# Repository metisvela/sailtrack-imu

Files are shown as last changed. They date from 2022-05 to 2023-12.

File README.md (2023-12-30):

<p align="center">
  
</p>

<p align="center">
  
  
</p>

# SailTrack IMU

SailTrack IMU is a component of the SailTrack system, it manages IMU data, providing attitude information of the boat. To learn more about the SailTrack project, please visit the [project repository](https://github.com/metisvela/sailtrack).

The SailTrack IMU module is based on a battery powered LilyGo TTGO T7, consisting of an [ESP32](https://www.espressif.com/en/products/socs/esp32) microcontroller, connected to an IMU breakout board. For a more detailed hardware description of the module, please refer to the [Bill Of Materials](hardware/BOM.csv). The 3D-printable enclosure con be found [here](hardware/STL).

The module performs the following tasks:

* It gets the IMU data coming from the accelerometer, gyrocope and magnetometer, and fuses them, using a Kalman filter, to obtain accurate and clean attitude infromation of the boat. The filtered metrics are then sent to the SailTrack Network.

<p align="center">
  <br/>
  
</p>

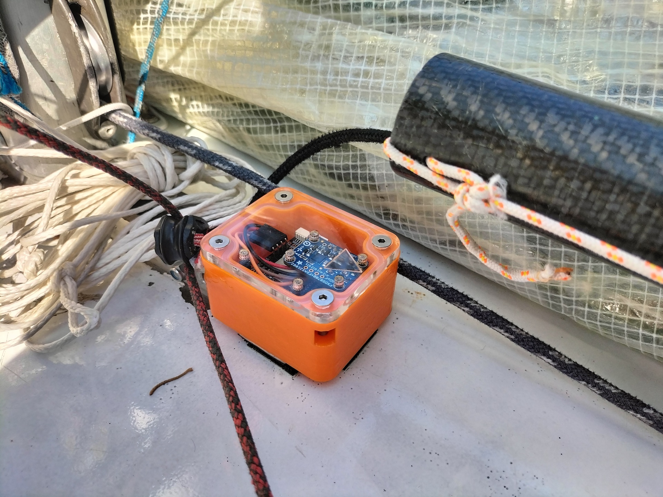
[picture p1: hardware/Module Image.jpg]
module-image


## Installation

Follow the instructions below to get the SailTrack IMU firmware correctly installed. If you encounter any problem, please [open an issue](https://github.com/metisvela/sailtrack-imu/issues/new).

1. [Install PlatformIO Core](https://docs.platformio.org/en/latest/core/installation/index.html).
2. Clone the SailTrack IMU repository:
   ```
   git clone https://github.com/metisvela/sailtrack-imu.git 
   ``` 
3. Cd into the directory:
   ```
   cd sailtrack-imu
   ```
4. **(macOS ONLY)** Uncomment the commented lines after "Patch for macOS" in the `platformio.ini` file.
5. Connect the module with an USB cable.
6. **(OPTIONAL BUT HIGHLY RECCOMENDED)** Calibrate the IMU:
   1. [Install MotionCal](https://www.pjrc.com/store/prop_shield.html).
   2. Flash the calibration firmware:
      ```
      pio run -e motioncal.cpp
      ```
   3. Open MotionCal and select the serial port the module is connected to.
   4. Start rotating the module doing circular movements in all possible directions until the `Gaps` value gets below 1%.
   5. Press the `Send Cal` button and wait until a green check appears. *Note: if the check doesn't appear after some seconds, press the `Send Cal` button again.*
7. Finally, flash the firmware:
   ```
   pio run
   ```

## Usage

Once the firmware is uploaded the module can work with the SailTrack system. When SailTrack IMU is turned on, a LED start to blink to notify the user about the connection status with SailTrack Core. Then, if the connection is successful, the LED stays on, otherwise the module will put itself to sleep, and it will try to connect later. Once the module is connected it will automatically start sending measurements.

## Contributing

Contributors are welcome. If you are a student of the University of Padova, please apply for the Metis Sailing Team team in the [website](http://metisvela.dii.unipd.it), specifying in the appliaction form that you are interested in contributing to the SailTrack Project. If you are not a student of the University of Padova, feel free to open Pull Requests and Issues to contribute to the project.

## License

Copyright © 2023, [Metis Sailing Team](https://github.com/metisvela). SailTrack IMU is available under the [GPL-3.0 license](https://www.gnu.org/licenses/gpl-3.0.en.html). See the LICENSE file for more info.

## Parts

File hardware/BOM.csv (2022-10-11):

Part Name | Total Quantity Required | Note
LilyGo TTGO T7 v1.3 ESP32-WROVER-B + BMS | 1
Adafruit Precision NXP 9-DOF Breakout Board - FXOS8700 + FXAS21002 | 1
103040 LiPo Battery 1S 1200mAh | 1

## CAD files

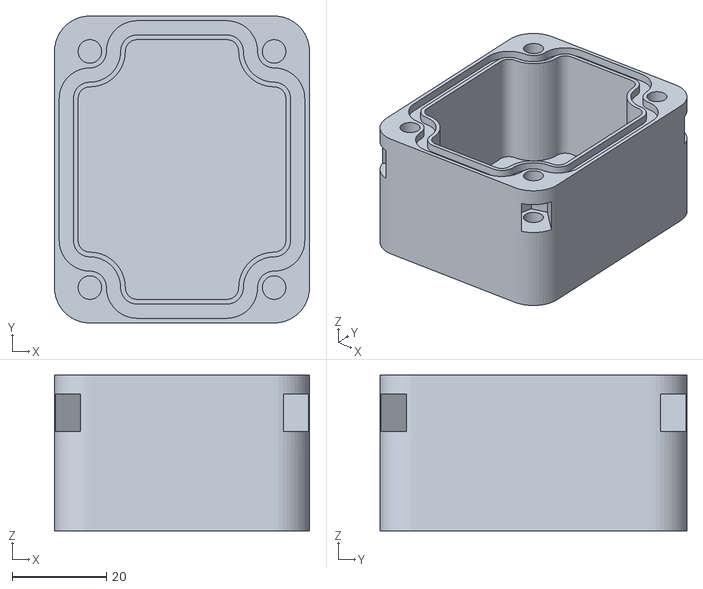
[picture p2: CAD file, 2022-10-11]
hardware/STL/Case Bottom.stl
54.0 x 65.0 x 33.0

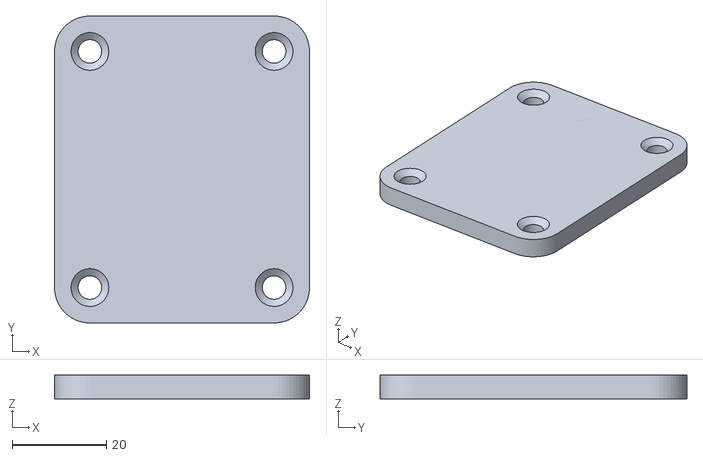
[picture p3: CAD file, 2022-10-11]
hardware/STL/Case Top.stl
54.0 x 65.0 x 5.00

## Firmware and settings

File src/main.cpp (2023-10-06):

#include <Arduino.h>
#include <SPI.h>
#include <SailtrackModule.h>
#include <Adafruit_FXOS8700.h>
#include <Adafruit_FXAS21002C.h>
#include <Adafruit_AHRS.h>
#include <Adafruit_Sensor_Calibration.h>

// -------------------------- Configuration -------------------------- //

#define MQTT_PUBLISH_FREQ_HZ		5
#define AHRS_UPDATE_FREQ_HZ			100

#define BATTERY_ADC_PIN 			35
#define BATTERY_ADC_RESOLUTION 		4095
#define BATTERY_ADC_REF_VOLTAGE 	1.1
#define BATTERY_ESP32_REF_VOLTAGE	3.3
#define BATTERY_NUM_READINGS 		32
#define BATTERY_READING_DELAY_MS	20

#define I2C_SDA_PIN 				27
#define I2C_SCL_PIN 				25

#define LOOP_TASK_INTERVAL_MS		1000 / AHRS_UPDATE_FREQ_HZ
#define MQTT_TASK_INTERVAL_MS	 	1000 / MQTT_PUBLISH_FREQ_HZ

// ------------------------------------------------------------------- //

SailtrackModule stm;
Adafruit_FXOS8700 fxos = Adafruit_FXOS8700(0x8700A, 0x8700B);
Adafruit_FXAS21002C fxas = Adafruit_FXAS21002C(0x0021002C);
Adafruit_NXPSensorFusion filter;
Adafruit_Sensor_Calibration_EEPROM cal;
Adafruit_Sensor *accelerometer, *gyroscope, *magnetometer;

float eulerX, eulerY, eulerZ;
float linearAccelX, linearAccelY, linearAccelZ;

class ModuleCallbacks: public SailtrackModuleCallbacks {
	void onStatusPublish(JsonObject status) {
		JsonObject battery = status.createNestedObject("battery");
		float avg = 0;
		for (int i = 0; i < BATTERY_NUM_READINGS; i++) {
			avg += analogRead(BATTERY_ADC_PIN) / BATTERY_NUM_READINGS;
			delay(BATTERY_READING_DELAY_MS);
		}
		battery["voltage"] = 2 * avg / BATTERY_ADC_RESOLUTION * BATTERY_ESP32_REF_VOLTAGE * BATTERY_ADC_REF_VOLTAGE;
	}
};

void mqttTask(void * pvArguments) {
	TickType_t lastWakeTime = xTaskGetTickCount();
	while (true) {
		StaticJsonDocument<STM_JSON_DOCUMENT_MEDIUM_SIZE> doc;

		JsonObject euler = doc.createNestedObject("euler");
		euler["x"] = eulerX;
		euler["y"] = eulerY;
		euler["z"] = eulerZ;

		JsonObject linearAccel = doc.createNestedObject("linearAccel");
		linearAccel["x"] = linearAccelX;
		linearAccel["y"] = linearAccelY;
		linearAccel["z"] = linearAccelZ;

		stm.publish("sensor/imu0", doc.as<JsonObjectConst>());

		vTaskDelayUntil(&lastWakeTime, pdMS_TO_TICKS(MQTT_TASK_INTERVAL_MS));
	}
}

void beginIMU() {
	Wire.setPins(I2C_SDA_PIN, I2C_SCL_PIN);
	fxos.begin();
	fxas.begin();
	accelerometer = fxos.getAccelerometerSensor();
	gyroscope = &fxas;
  	magnetometer = fxos.getMagnetometerSensor();
	Wire.setClock(400000);
}

void beginAHRS() {
	cal.begin();
	cal.loadCalibration();
	filter.begin(AHRS_UPDATE_FREQ_HZ);
}

void setup() {
	stm.begin("imu", IPAddress(192, 168, 42, 102), new ModuleCallbacks());
	beginIMU();
	beginAHRS();
	xTaskCreate(mqttTask, "mqttTask", STM_TASK_MEDIUM_STACK_SIZE, NULL, STM_TASK_MEDIUM_PRIORITY, NULL);
}

void loop() {
	TickType_t lastWakeTime = xTaskGetTickCount();
	sensors_event_t accelEvent, gyroEvent, magEvent;

	accelerometer->getEvent(&accelEvent);
	gyroscope->getEvent(&gyroEvent);
	magnetometer->getEvent(&magEvent);

	cal.calibrate(accelEvent);
	cal.calibrate(gyroEvent);
	cal.calibrate(magEvent);

	float gx, gy, gz;
	gx = gyroEvent.gyro.x * SENSORS_RADS_TO_DPS;
	gy = gyroEvent.gyro.y * SENSORS_RADS_TO_DPS;
	gz = gyroEvent.gyro.z * SENSORS_RADS_TO_DPS;

	float ax, ay, az;
	ax = accelEvent.acceleration.x / SENSORS_GRAVITY_STANDARD;
	ay = accelEvent.acceleration.y / SENSORS_GRAVITY_STANDARD;
	az = accelEvent.acceleration.z / SENSORS_GRAVITY_STANDARD;

	filter.update(gx, gy, gz, ax, ay, az, magEvent.magnetic.x, magEvent.magnetic.y, magEvent.magnetic.z);

	eulerX = filter.getRoll();
	eulerY = filter.getPitch();
	eulerZ = filter.getYaw();

	filter.getLinearAcceleration(&linearAccelX, &linearAccelY, &linearAccelZ); 

	vTaskDelayUntil(&lastWakeTime, pdMS_TO_TICKS(LOOP_TASK_INTERVAL_MS));
}

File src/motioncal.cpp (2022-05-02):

#include <Arduino.h>
#include <SPI.h>
#include <Adafruit_FXOS8700.h>
#include <Adafruit_FXAS21002C.h>
#include <Adafruit_Sensor_Calibration.h>

// -------------------------- Configuration -------------------------- //

#define I2C_SDA_PIN                 27
#define I2C_SCL_PIN                 25

// ------------------------------------------------------------------- //


Adafruit_FXOS8700 fxos = Adafruit_FXOS8700(0x8700A, 0x8700B);
Adafruit_FXAS21002C fxas = Adafruit_FXAS21002C(0x0021002C);
Adafruit_Sensor_Calibration_EEPROM cal;
Adafruit_Sensor *accelerometer, *gyroscope, *magnetometer;
int loopcount = 0;

byte calData[68];
byte calCount = 0;

uint16_t crc16Update(uint16_t crc, uint8_t a) {
    int i;
    crc ^= a;
    for (i = 0; i < 8; i++) {
        if (crc & 1) crc = (crc >> 1) ^ 0xA001;
        else crc = (crc >> 1);
    }
    return crc;
}

void receiveCalibration() {
    uint16_t crc;
    byte b, i;

    while (Serial.available()) {
        b = Serial.read();
        if (calCount == 0 && b != 117) return;
        if (calCount == 1 && b != 84) {
            calCount = 0;
            return;
        }

        calData[calCount++] = b;
        if (calCount < 68) return;

        crc = 0xFFFF;
        for (i=0; i < 68; i++) 
            crc = crc16Update(crc, calData[i]);
        if (!crc) {
            float offsets[16];
            memcpy(offsets, calData + 2, 16 * 4);
            cal.accel_zerog[0] = offsets[0];
            cal.accel_zerog[1] = offsets[1];
            cal.accel_zerog[2] = offsets[2];
            
            cal.gyro_zerorate[0] = offsets[3];
            cal.gyro_zerorate[1] = offsets[4];
            cal.gyro_zerorate[2] = offsets[5];
            
            cal.mag_hardiron[0] = offsets[6];
            cal.mag_hardiron[1] = offsets[7];
            cal.mag_hardiron[2] = offsets[8];

            cal.mag_field = offsets[9];
            
            cal.mag_softiron[0] = offsets[10];
            cal.mag_softiron[1] = offsets[13];
            cal.mag_softiron[2] = offsets[14];
            cal.mag_softiron[3] = offsets[13];
            cal.mag_softiron[4] = offsets[11];
            cal.mag_softiron[5] = offsets[15];
            cal.mag_softiron[6] = offsets[14];
            cal.mag_softiron[7] = offsets[15];
            cal.mag_softiron[8] = offsets[12];

            cal.saveCalibration();

            calCount = 0;
            return;
        }

        for (i=2; i < 67; i++) {
            if (calData[i] == 117 && calData[i+1] == 84) {
                calCount = 68 - i;
                memmove(calData, calData + i, calCount);
                return;
            }
        }

        if (calData[67] == 117) {
            calData[0] = 117;
            calCount = 1;
        } else calCount = 0;
    }
}

void setup(void) {
    Serial.begin(115200);
    Wire.setPins(I2C_SDA_PIN, I2C_SCL_PIN);
    cal.begin();
    cal.loadCalibration();
    fxos.begin();
	fxas.begin();
	accelerometer = fxos.getAccelerometerSensor();
	gyroscope = &fxas;
  	magnetometer = fxos.getMagnetometerSensor();
	Wire.setClock(400000);
}

void loop() {
    sensors_event_t accelEvent, gyroEvent, magEvent;

    accelerometer->getEvent(&accelEvent);
	gyroscope->getEvent(&gyroEvent);
	magnetometer->getEvent(&magEvent);
    
    Serial.print("Raw:");
    Serial.print(int(accelEvent.acceleration.x * 8192 / SENSORS_GRAVITY_STANDARD)); Serial.print(",");
    Serial.print(int(accelEvent.acceleration.y * 8192 / SENSORS_GRAVITY_STANDARD)); Serial.print(",");
    Serial.print(int(accelEvent.acceleration.z * 8192 / SENSORS_GRAVITY_STANDARD)); Serial.print(",");
    Serial.print(int(gyroEvent.gyro.x * SENSORS_RADS_TO_DPS * 16)); Serial.print(",");
    Serial.print(int(gyroEvent.gyro.y * SENSORS_RADS_TO_DPS * 16)); Serial.print(",");
    Serial.print(int(gyroEvent.gyro.z * SENSORS_RADS_TO_DPS * 16)); Serial.print(",");
    Serial.print(int(magEvent.magnetic.x * 10)); Serial.print(",");
    Serial.print(int(magEvent.magnetic.y * 10)); Serial.print(",");
    Serial.print(int(magEvent.magnetic.z * 10)); Serial.println();

    loopcount++;

    receiveCalibration();

    if (loopcount == 50 || loopcount > 100) {
        Serial.print("Cal1:");
        for (int i = 0; i < 3; i++) {
            Serial.print(cal.accel_zerog[i], 3); 
            Serial.print(",");
        }
        for (int i = 0; i < 3; i++) {
            Serial.print(cal.gyro_zerorate[i], 3);
            Serial.print(",");
        }  
        for (int i = 0; i < 3; i++) {
            Serial.print(cal.mag_hardiron[i], 3); 
            Serial.print(",");
        }  
        Serial.println(cal.mag_field, 3);
        loopcount++;
    }
    if (loopcount >= 100) {
        Serial.print("Cal2:");
        for (int i = 0; i < 9; i++) {
            Serial.print(cal.mag_softiron[i], 4); 
            if (i < 8) Serial.print(',');
        }
        Serial.println();
        loopcount = 0;
    }

    delay(10); 
}

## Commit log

2021-07-11 Added submodule lib/sailtrack-sensor
2021-07-20 Updated submodule lib/sailtrack-sensor
2022-02-17 Add hardware files
    [BOM.csv, case-bottom.stl, case-top.stl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]
2022-04-01 add Kalman filter
2022-04-08 Update code with a new task only for IMU filtering
2022-04-12 Changes:
    Update platformio.ini
    Add calibration script
    Fix Adafruit AHRS usage
    [main.cpp, motioncal.cpp]
2022-04-13 Remove connection LED pin define
2022-04-14 Fix int divide by zero exeption and other minor bugs. Imu seems to work pretty good
    [main.cpp]
2022-04-20 Changes:
    Improve battery voltage reading
    Improve task timing
2022-04-29 Adapt to new IMU module
2022-06-17 Rename platformio parameter + Add 3d files
    [Case Bottom.stl, Case Top.stl, case-bottom.stl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]
2022-06-20 Update hardware files
    [Case Top.stl]
2022-09-02 rework on kalman function params
    [main.cpp]
